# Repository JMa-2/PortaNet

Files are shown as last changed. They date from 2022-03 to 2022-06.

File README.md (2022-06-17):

# ***PortaNet Guide***
---
## *TABLE OF CONTENTS*
- [Introduction](#introduction)
- [Hardware](#hardware)
    - [Hardware General](#hardware-general)
    - [Hardware Tools](#hardware-tools)
    - [Schematic](#schematic)
    - [PCB Layout](#pcb-layout)
    - [BOM](#bom)
- [Software](#software)
    - [Software General](#software-general)
    - [Software Tools](#software-tools)
    - [Architecture](#architecture)
    - [Building](#building--flashing)
- [How to Use](#how-to-use)
    - [Use General](#use-general)
    - [PuTTy](#putty)
    - [Console Commands](#console-commands)
<br>
<br>
<br>

## *INTRODUCTION*
The PortaNet is a wifi access point (AP) using the Espressif ESP32-C3FH4 microcontroller. The PortaNet holds the shape and connection types of a typical USB stick. The AP's settings can be modified via a serial console. At this point PuTTy is the only tested terminal emulator software for use with PortaNet.

<br>

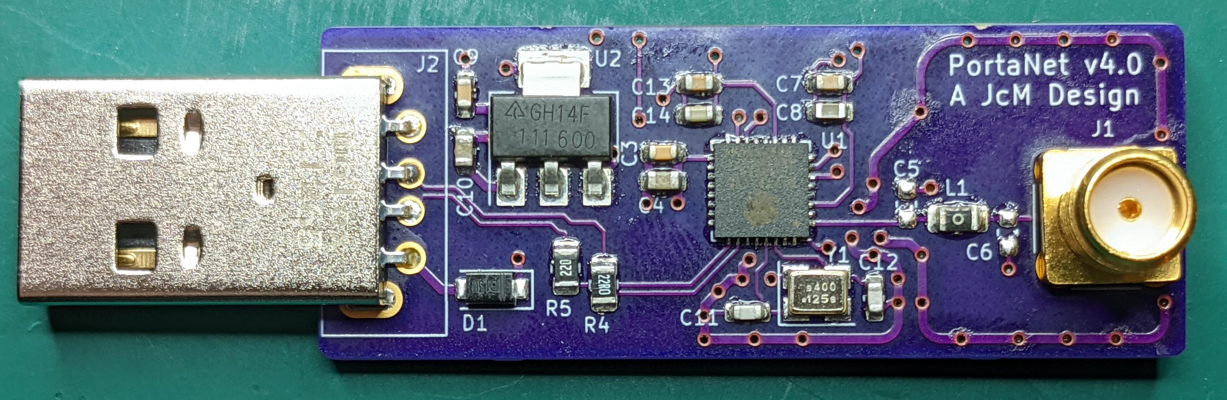
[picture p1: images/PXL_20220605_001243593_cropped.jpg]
PortaNet v4.0


<br>
<br>
<br>

## *HARDWARE*
### Hardware General
The critical component consists of the [Espressif ESP32-C3FH4](https://www.espressif.com/en/products/socs/esp32-c3). The ESP32-C3FH4 microcontroller is a ESP32-C3 variant with 4MB internal flash. Simply buying the "normal" ESP32-C3 variant will not suffice due to the lack of internal flash.

The design utilizes a 50 &Omega; impedance, 2.4 GHz wifi antenna. Antennas such as [this](https://www.amazon.com/gp/product/B07D1Z3W7T/ref=ppx_yo_dt_b_search_asin_title?ie=UTF8&psc=1) and [this](https://www.amazon.com/gp/product/B0991PKTDL/ref=ppx_yo_dt_b_search_asin_title?ie=UTF8&psc=1) have worked successfully. There is an unused &pi;-matching circuit that could aid in supporting other antennas.

### Hardware Tools
KiCad v6 was utilized as the EDA tool. The KiCad project can be found in the [hardware directory](hardware/kicad/PortaNet/). Additionally my [KiCad Library](http://192.168.1.19:3000/JMa/KiCad_Library) may contain needed symbols and footprints that the project references.

### Schematic
The current schematic can be seen [here](hardware/kicad/PortaNet_SCH.pdf). 

On page 2 of the schematic, the only oddity worth explaining is the NC of C2. Having C2 installed results in the GPIO9 (pin 15) being pulled low. Resulting in the firmware getting stuck in the bootloader.

On page 3 of the schematic, lives the unused &pi;-matching circuit labeled `Antenna`. If the &pi;-matching circuit does not want to be used, then `L1` should be shorted with a 0 &Omega; resistor.

On page 3 also lives the `Crystal` section. While the load capacitors are labeled 7pF, 8pF caps work with no issues thus far. 

### PCB Layout
The board layout consists of 4 layers, with components on both the top and bottom layers. 

The layer structure consists of the top layer being a signal layer, the second and third layer being GND layers, and the bottom layer being a PWR/signal layer. The top layer or layer 1 of the board is structured to isolate noise sources from other hardware sections. The sub-circuits on the top layer are split into PWR/USB, microcontroller (uC), crystal (XTAL), and radio frequency (RF) sections. GND traces with vias surround the RF and XTAL sections of the top layer.

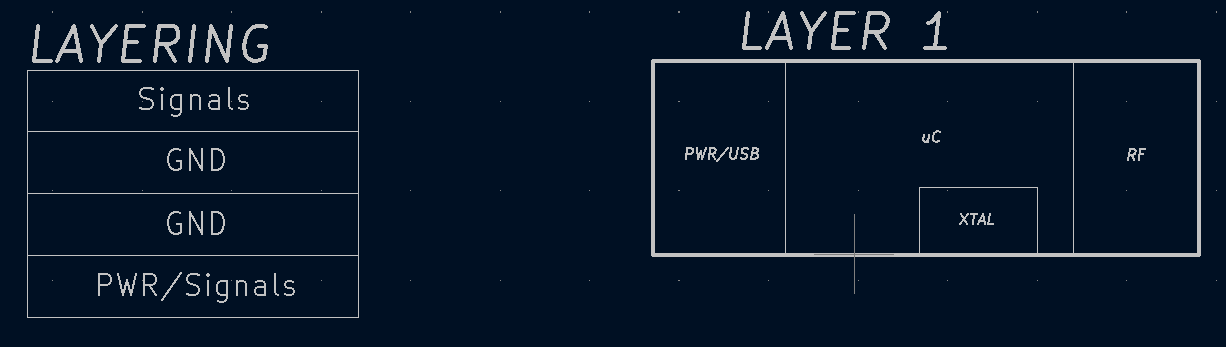
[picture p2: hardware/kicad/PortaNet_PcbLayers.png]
PCB Layout

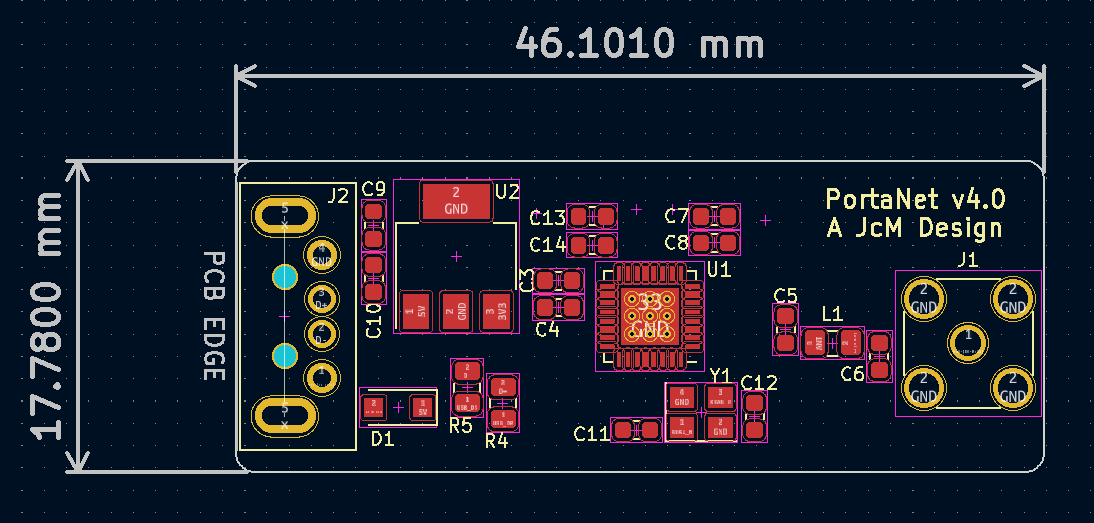
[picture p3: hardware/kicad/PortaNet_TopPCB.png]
Top Layer Routing


### BOM
The BOM can be found [here](hardware/kicad/PortaNet/PortaNet.csv). As well as a copy and paste is below. It is again important to note that **the ESP32-C3 part purchased must be a part that contains internal flash.**

| Ref | Qnty | Value | Cmp name | Footprint |
|---|---|---|---|---|
| C1, | 1 | 1uF | C_Small | Capacitor_SMD:C_0603_1608Metric |
| C2, | 1 | NC | C_Small | Capacitor_SMD:C_0603_1608Metric |
| C3, C7, C13, | 3 | 0.1uF | C_Small | Capacitor_SMD:C_0603_1608Metric |
| C4, C8, C10, C14, | 4 | 10uF | C_Small | Capacitor_SMD:C_0603_1608Metric |
| C5, C6, | 2 | TBD | C_Small | Capacitor_SMD:C_0603_1608Metric |
| C9, | 1 | .1uF | C_Small | Capacitor_SMD:C_0603_1608Metric |
| C11, C12, | 2 | 7pF | C_Small | Capacitor_SMD:C_0603_1608Metric |
| D1, | 1 | DSS13UTR | D_Schottky | Diode_SMD:D_SOD-123F |
| J1, | 1 | SMA | Conn_Coaxial | Connector_Coaxial:SMA_Amphenol_132134_Vertical |
| J2, | 1 | Molex 0480370001 | USB_A | JoesFootprints:Molex_0480370001 |
| L1, | 1 | TBD | L | Inductor_SMD:L_0805_2012Metric_Pad1.15x1.40mm_HandSolder |
| R1, R2, R3, | 3 | 10k | R_Small_US | Resistor_SMD:R_0805_2012Metric |
| R4, R5, | 2 | 22 | R_Small_US | Resistor_SMD:R_0805_2012Metric |
| SW1, | 1 | 434133025816 | SW_SPST | Button_Switch_SMD:SW_Push_1P1T_NO_Vertical_Wuerth_434133025816  |
| U1, | 1 | ESP32-C3 | ESP32-C3 | Package_DFN_QFN:QFN-32-1EP_5x5mm_P0.5mm_EP3.3x3.3mm_ThermalVias |
| U2, | 1 | AP2114HA-3.3TRG1 | AP2114HA-3.3TRG1 | Package_TO_SOT_SMD:SOT-223-3_TabPin2 |
| Y1, | 1 | FL400WFQA1 | Crystal_GND24 | Crystal:Crystal_SMD_3225-4Pin_3.2x2.5mm |

<br>
<br>
<br>

## *SOFTWARE*
### Software General
The firmware is written in C using [Espressif's IOT Development Framework (ESP-IDF)](https://www.espressif.com/en/products/sdks/esp-idf#:~:text=ESP%2DIDF%20is%20Espressif's%20official,as%20C%20and%20C%2B%2B.). The software utilizes [FreeRTOS](https://www.freertos.org/) as part of the ESP-IDF as well. 

### Software Tools
The software used `ESP-IDF v5.0-dev-3032-g7e71c0cff2-dirty`. The ESP-IDF can be found [here](https://github.com/espressif/esp-idf).

### Architecture
The software utilizes an RTOS variation of [A JcM Architecture](http://192.168.1.19:3000/JMa/JcmArch). Architecture formats can be seen [here](firmware/)

Two threads exists in the software. The first thread, which has the highest priority, is the `Access Point Thread`. The second thread, which has a lower priority compared to the `Access Point Thread`, is the `Console Thread`. The `Access Point Thread` is controlling the wifi soft-AP and the `Console Thread` is controlling the serial console processes that make requests to the `Access Point Interface`. 

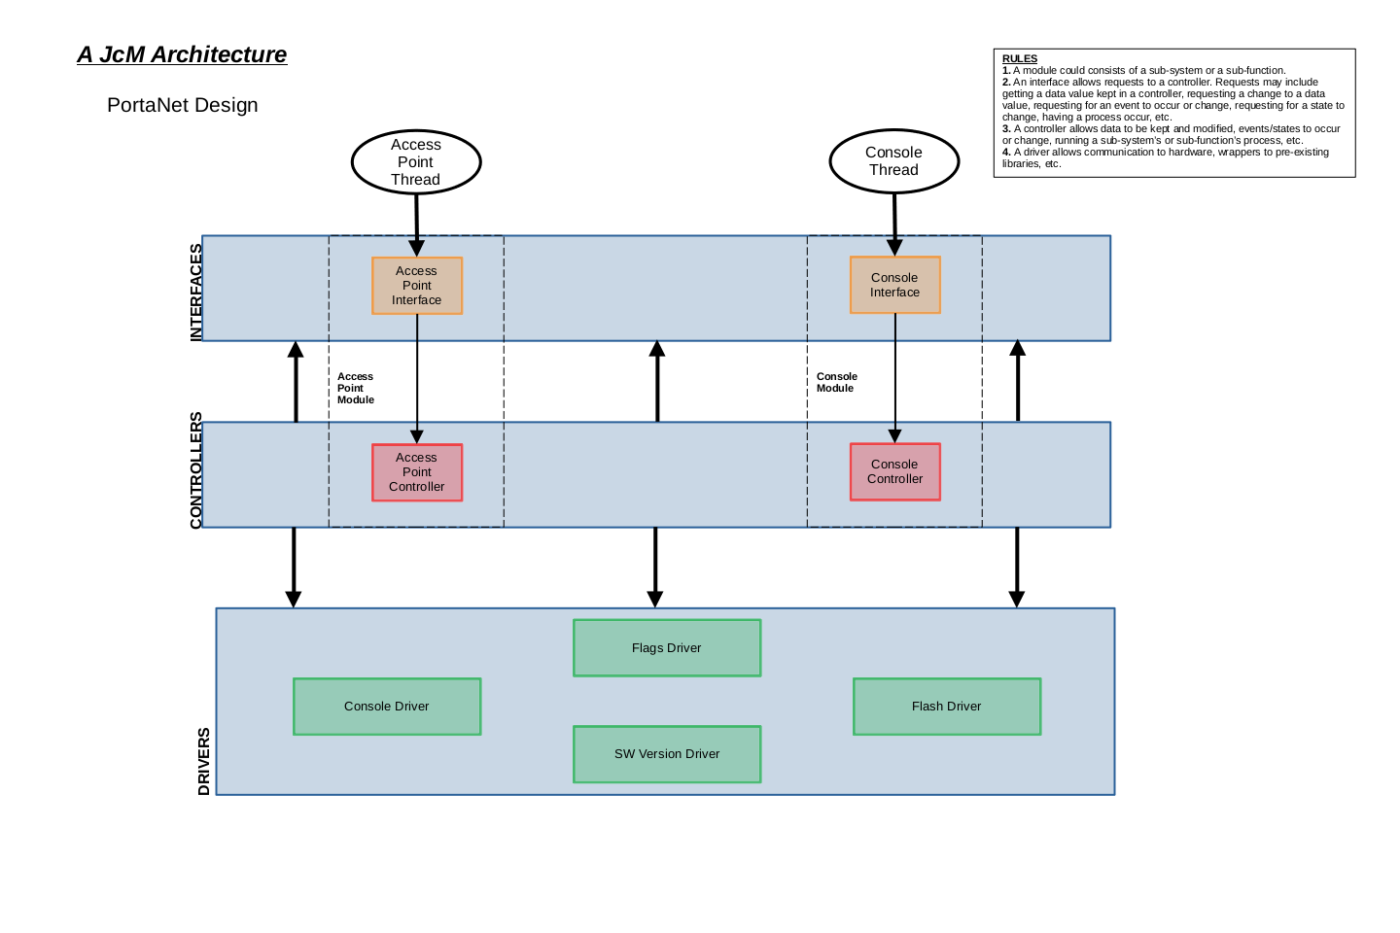
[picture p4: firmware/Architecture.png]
PortaNet SW Architecture


### Building & Flashing
1. Clone the repo<br>
`git clone http://192.168.1.19:3000/JMa/PortaNet.git`

2. Enter the firmware folder<br>
`cd PortaNet/firmware/PortaNet/`

3. Source the ESP-IDF export script from proper location<br>
example: `. ~/esp-idf/export.sh`

4. Ensure the target is set to the ESP32-C3<br>
`idf.py set-target esp32c3`

5. Build the project<br>
`idf.py build`

6. Flash the device<br>
`idf.py -p PORT flash`

<br>

If issues arise, Espressif has good documentation located [here](https://docs.espressif.com/projects/esp-idf/en/latest/esp32c3/get-started/linux-macos-setup.html).

<br>
<br>
<br>

## *HOW TO USE*
### Use General
Since the device uses USB 2.0, the operating voltage is 5V. Typical PC USB receptacles work just fine and even phone/device charging bricks should work without issue. The device draws less that 100mA so there shouldn't be power rating issues to monitor.

### PuTTy
At this point, PuTTy is the only terminal emulator that the device has really been tested with. PicoCom, the linux utility, appears to work as well.

PuTTy can be downloaded from [here](https://www.putty.org/) and it is widely used enough to easily find tutorials via Google or Youtube. 

### Console Commands
`help`<br>
Print the list of registered commands.

`status`<br>
Status of the AP which includes info such as the SSID, password, max number of connections, and wifi channel.

`reset`<br>
Reset the AP to its default credentials

`on`<br>
Turn on the AP.

`off`<br>
Turn off the AP.

`devices`<br>
Show info on currently connected devices.

`ssid <NAME>`<br>
Request new SSID of AP.

`password <PW>`<br>
Request new password of AP.

`maxconn <#>`<br>
Request new number of max connection of the AP.

`restart`<br>
Request the AP to restart.

`version`<br>
Request the current software version.

`channel <#>`<br>
Request new wifi channel of the AP.

<br>
<br>
<br>

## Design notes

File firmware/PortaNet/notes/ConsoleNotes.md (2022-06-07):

# ***CONSOLE NOTES***
***

## *INTERFACE*
`TaskConsole`

- interface to the task
<br><br/>

***

## *CONTROLLER*
`ConsoleController`

- handles the console processes to execute
<br><br/>

`RegisterAllCommands`

- registers all wanted commands
<br><br/>

`CmdReset`

- command function to request a reset of the wifi access point to its defualt credentials 
<br><br/>

`RegisterReset`

- register the reset command
<br><br/>

`CmdRestart`

- command function to request a restart of the wifi access point
<br><br/>

`RegisterRestart`

- register the restart command
<br><br/>

`CmdOn`

- command function to request the wifi access point on
<br><br/>

`RegisterOn`

- register the on command
<br><br/>

`CmdOff`

- command function to request the wifi access point off
<br><br/>

`RegisterOff`

- register the off command
<br><br/>

`CmdStatus`

- command function to request the status of the wifi access point. The status info should include the network name, the network password, the max number of connected devices allowed, and the current wifi channel.
<br><br/>

`RegisterStatus`

- register the status command
<br><br/>

`CmdDevices`

- command function to show the info of the currently connected stations/devices
<br><br/>

`RegisterDevices`

- register the devices command
<br><br/>

`CmdSsid`

- command function to request a change to the wifi access point's SSID and restart the wifi access point
- input arg of string
<br><br/>

`RegisterSsid`

- register the SSID command
<br><br/>

`CmdPassword`

- command function to request a change to the wifi access point's password and restart the wifi access point
- input arg of string
<br><br/>

`RegisterPassword`

- register the password command
<br><br/>

`CmdMaxConn`

- command function to request a change to the wifi access point's max number of connections and restart the wifi access point
- input arg of int
<br><br/>

`RegisterMaxConn`

- register the maxconn command
<br><br/>

`CmdSwVersion`

- command function to request the version of the firmware in use
<br><br/>

`RegisterSwVersion`

- register the software version command
<br><br/>

`CmdChannel`

- command function to request the wifi channel be changed
<br><br/>

`RegisterChannel`

- register the wifi channel change command

***

## *CONSOLE DRIVER*
`InitConsole`

- initialises the console, should only need to be called once
<br><br/>

***

## *COMMANDS*
`reset`

- resets the wifi access point with the defualt credentials
<br><br/>

`restart`

- restart the wifi access point 
<br><br/>

`on`

- turn on the wifi access point
<br><br/>

`off`

- turn off the wifi access point
<br><br/>

`status`

- show the status of the network if it running. The status info should include the network name, the network password, the max number of connected devices allowed, and the current wifi channel.
<br><br/>

`devices`

- shows the currently connected devices
<br><br/>

`ssid <newssid>`

- change the ssid name and restart the wifi access point
<br><br/>

`password <password>`

- change the password and restart the wifi access point
<br><br/>

`maxconn <connections>`

- change the number of max device connections and restart the wifi access point 
<br><br/>

`version`

- shows the current version of firmware

`channel <#>`

- change the wifi channel and restart the access point

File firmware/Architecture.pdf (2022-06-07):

## Access Point Thread

### Access Point

### Interface

### Access Point Controller

### Flags Driver

Console Driver | Flash Driver

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
## RIV

E

R

S

Access
Point
Module

## Console Thread

### Console

### Interface

### Console

### Controller

Console
Module

# A JcM Architecture

# PortaNet Design

RULES
1. A module could consists of a sub-system or a sub-function.

### 2. An interface allows requests to a controller. Requests may include

getting a data value kept in a controller, requesting a change to a data value, requesting for an event to occur or change, requesting for a state to change, having a process occur, etc.

### 3. A controller allows data to be kept and modified, events/states to occur

or change, running a sub-system’s or sub-function’s process, etc.

### 4. A driver allows communication to hardware, wrappers to pre-existing

libraries, etc.

### SW Version Driver

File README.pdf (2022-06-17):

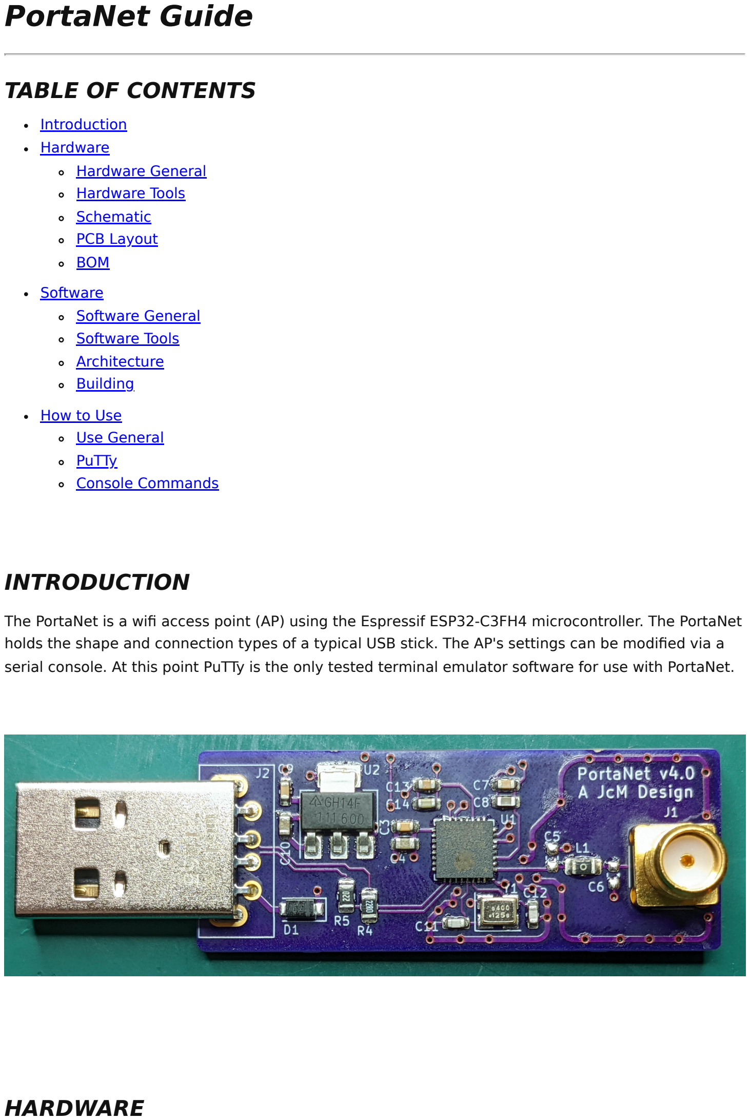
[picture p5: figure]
PortaNet Guide; TABLE OF CONTENTS; Introduction Hardware Hardware General Hardware Tools Schematic PCB Layout BOM; Software Software General Software Tools Architecture Building; How to Use Use General PuTTy Console Commands; INTRODUCTION; HARDWARE

The PortaNet is a wifi access point (AP) using the Espressif ESP32-C3FH4 microcontroller. The PortaNet holds the shape and connection types of a typical USB stick. The AP's settings can be modified via a serial console. At this point PuTTy is the only tested terminal emulator software for use with PortaNet.

Hardware General

The critical component consists of the Espressif ESP32-C3FH4. (https://www.espressif.com/en/products/socs/esp32-c3) The ESP32-C3FH4 microcontroller is a ESP32-C3 variant with 4MB internal flash. Simply buying the "normal" ESP32-C3 variant will not suffice due to the lack of internal flash.

The design utilizes a 50 Ω impedance, 2.4 GHz wifi antenna. Antennas such as this (https://www.amazon.com/gp/product/B07D1Z3W7T/ref=ppx_yo_dt_b_search_asin_title?ie=UTF8&psc=1) and this (https://www.amazon.com/gp/product/B0991PKTDL/ref=ppx_yo_dt_b_search_asin_title?ie=UTF8&psc=1) have worked successfully. There is an unused π-matching circuit that could aid in supporting other antennas.

Hardware Tools

KiCad v6 was utilized as the EDA tool. The KiCad project can be found in the hardware directory. (http://localhost:33777/hardware/kicad/PortaNet/) Additionally my KiCad Library (http://192.168.1.19:3000/JMa/KiCad_Library) may contain needed symbols and footprints that the project references.

Schematic

The current schematic can be seen here. (http://localhost:33777/hardware/kicad/PortaNet_SCH.pdf)

On page 2 of the schematic, the only oddity worth explaining is the NC of C2. Having C2 installed results in the GPIO9 (pin 15) being pulled low. Resulting in the firmware getting stuck in the bootloader.

On page 3 of the schematic, lives the unused π-matching circuit labeled Antenna . If the π-matching circuit does not want to be used, then L1 should be shorted with a 0 Ω resistor.

On page 3 also lives the Crystal section. While the load capacitors are labeled 7pF, 8pF caps work with no issues thus far.

PCB Layout

The board layout consists of 4 layers, with components on both the top and bottom layers.

The layer structure consists of the top layer being a signal layer, the second and third layer being GND layers, and the bottom layer being a PWR/signal layer. The top layer or layer 1 of the board is structured to isolate noise sources from other hardware sections. The sub-circuits on the top layer are split into PWR/USB, microcontroller (uC), crystal (XTAL), and radio frequency (RF) sections. GND traces with vias surround the RF and XTAL sections of the top layer.


BOM

The BOM can be found here. (http://localhost:33777/hardware/kicad/PortaNet/PortaNet.csv) As well as a copy and paste is below. It is again important to note that the ESP32-C3 part purchased must be a part that contains internal flash.

Ref | Qnty | Value | Cmp name | Footprint
C1, | 1 | 1uF | C_Small | Capacitor_SMD:C_0603_1608Metric
C2, | 1 | NC | C_Small | Capacitor_SMD:C_0603_1608Metric

C3,
C7, C13, | 3 | 0.1uF | C_Small | Capacitor_SMD:C_0603_1608Metric

C4,
C8,
C10,
C14,
4 | 10uF | C_Small | Capacitor_SMD:C_0603_1608Metric

C5,
C6,
| 2 | TBD | C_Small | Capacitor_SMD:C_0603_1608Metric
C9, | 1 | .1uF | C_Small | Capacitor_SMD:C_0603_1608Metric

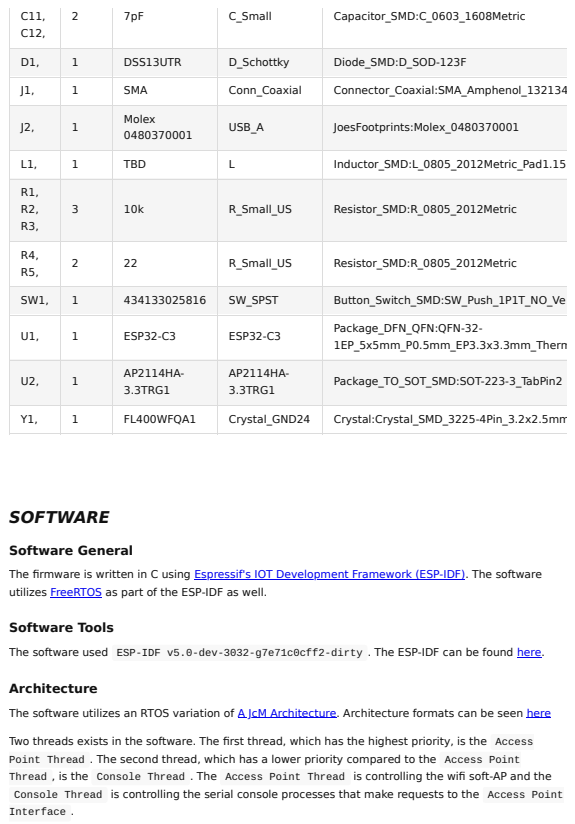
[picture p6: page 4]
C_Small; Capacitor_SMD:C_0603_1608Metric; DSS13UTR; D_Schottky; Diode_SMD:D_SOD-123F; SMA; Conn_Coaxial; Connector_Coaxial:SMA_Amphenol_132134; Molex 0480370001; USB_A; JoesFootprints:Molex_0480370001; TBD; Inductor_SMD:L_0805_2012Metric_Pad1.15; R_Small_US; Resistor_SMD:R_0805_2012Metric; SW_SPST; Button_Switch_SMD:SW_Push_1P1T_NO_Ve; ESP32-C3; Package_DFN_QFN:QFN-32-; 1EP_5x5mm_P0.5mm_EP3.3x3.3mm_Therm; AP2114HA- 3.3TRG1; Package_TO_SOT_SMD:SOT-223-3_TabPin2; FL400WFQA1; Crystal_GND24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

The firmware is written in C using Espressif's IOT Development Framework (ESP-IDF). (https://www.espressif.com/en/products/sdks/esp-idf) The software
utilizes FreeRTOS (https://www.freertos.org/) as part of the ESP-IDF as well.

The software used ESP-IDF v5.0-dev-3032-g7e71c0cff2-dirty . The ESP-IDF can be found here. (https://github.com/espressif/esp-idf)

The software utilizes an RTOS variation of A JcM Architecture. (http://192.168.1.19:3000/JMa/JcmArch) Architecture formats can be seen here (http://localhost:33777/firmware/)

Two threads exists in the software. The first thread, which has the highest priority, is the Access
Point Thread . The second thread, which has a lower priority compared to the Access Point
Thread , is the Console Thread . The Access Point Thread is controlling the wifi soft-AP and the
Console Thread is controlling the serial console processes that make requests to the Access Point
Interface .

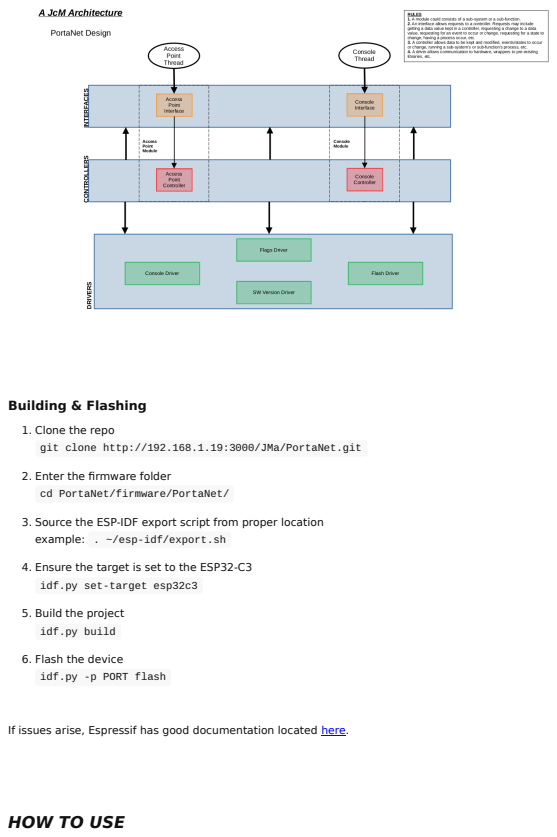
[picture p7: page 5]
Building & Flashing

1. Clone the repo
git clone http://192.168.1.19:3000/JMa/PortaNet.git

2. Enter the firmware folder
cd PortaNet/firmware/PortaNet/

3. Source the ESP-IDF export script from proper location
example: . ~/esp-idf/export.sh

4. Ensure the target is set to the ESP32-C3
idf.py set-target esp32c3

5. Build the project
idf.py build

6. Flash the device
idf.py -p PORT flash

If issues arise, Espressif has good documentation located here. (https://docs.espressif.com/projects/esp-idf/en/latest/esp32c3/get-started/linux-macos-setup.html)

HOW TO USE

Use General

Since the device uses USB 2.0, the operating voltage is 5V. Typical PC USB receptacles work just fine and even phone/device charging bricks should work without issue. The device draws less that 100mA so there shouldn't be power rating issues to monitor.

PuTTy

At this point, PuTTy is the only terminal emulator that the device has really been tested with. PicoCom, the linux utility, appears to work as well.

PuTTy can be downloaded from here (https://www.putty.org/) and it is widely used enough to easily find tutorials via Google or Youtube.

Console Commands

help
Print the list of registered commands.

status
Status of the AP which includes info such as the SSID, password, max number of connections, and wifi channel.

reset
Reset the AP to its default credentials

on
Turn on the AP.

off
Turn off the AP.

devices
Show info on currently connected devices.

ssid <NAME>
Request new SSID of AP.

password <PW>
Request new password of AP.

maxconn <#>
Request new number of max connection of the AP.

restart
Request the AP to restart.

version
Request the current software version.

channel <#>
Request new wifi channel of the AP.

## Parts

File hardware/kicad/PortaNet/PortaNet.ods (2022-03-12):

Component Count: | 32
Ref | Qnty | Value | Cmp name | Footprint | Description | Vendor
AE1, | 1 | ANT3216LL00R2400A | Antenna_Shield | JoesFootprints:ANT3216LL00R2400A | Antenna with extra pin for shielding
C3, | 1 | 0.1uF | C_Small | Capacitor_SMD:C_0603_1608Metric | Unpolarized capacitor, small symbol
C4, C10, | 2 | 10uF | C_Small | Capacitor_SMD:C_0603_1608Metric | Unpolarized capacitor, small symbol
C9, | 1 | .1uF | C_Small | Capacitor_SMD:C_0603_1608Metric | Unpolarized capacitor, small symbol
C11, C12, | 2 | 7pF | C_Small | Capacitor_SMD:C_0603_1608Metric | Unpolarized capacitor, small symbol
D1, D4, | 2 | DSS13UTR | D_Schottky | Diode_SMD:D_SOD-123F | Schottky diode
D2, | 1 | L196L-UEC-TR | LED | LED_SMD:LED_0603_1608Metric | Light emitting diode
D3, | 1 | L196L-QYC-TR | LED | LED_SMD:LED_0603_1608Metric | Light emitting diode
J1, | 1 | UART | Conn_01x03 | Connector_PinSocket_2.54mm:PinSocket_1x03_P2.54mm_Vertical | Generic connector, single row, 01x03, script generated (kicad-library-utils/schlib/autogen/connector/)
J2, | 1 | Molex 0480370001 | USB_A | JoesFootprints:Molex_0480370001 | USB Type A connector
J3, | 1 | OLED_PINS | Conn_01x04 | JoesFootprints:OLED_0.91in_i2c | Generic connector, single row, 01x04, script generated (kicad-library-utils/schlib/autogen/connector/)
J4, | 1 | GRPB052VWVN-RC | Conn_ARM_JTAG_SWD_10 | Connector_PinHeader_1.27mm:PinHeader_2x05_P1.27mm_Vertical | Cortex Debug Connector, standard ARM Cortex-M SWD and JTAG interface
R1, | 1 | 10k | R_Small_US | Resistor_SMD:R_0805_2012Metric | Resistor, small US symbol
R2, R3, R4, | 3 | 0 | R_Small_US | Resistor_SMD:R_0805_2012Metric | Resistor, small US symbol
R5, R6, | 2 | 4.7k | R_Small_US | Resistor_SMD:R_0805_2012Metric | Resistor, small US symbol
R7, R8, | 2 | 22 | R_Small_US | Resistor_SMD:R_0805_2012Metric | Resistor, small US symbol
R9, R10, | 2 | 1k | R_Small_US | Resistor_SMD:R_0805_2012Metric | Resistor, small US symbol
TP3, TP4, TP5, | 3 | TestPoint | TestPoint | TestPoint:TestPoint_Pad_1.0x1.0mm | test point
U1, | 1 | ESP32-C3 | ESP32-C3 | Package_DFN_QFN:QFN-32-1EP_5x5mm_P0.5mm_EP3.3x3.3mm_ThermalVias
U2, | 1 | AP2114HA-3.3TRG1 | AP2114HA-3.3TRG1 | Package_TO_SOT_SMD:SOT-223-3_TabPin2
Y1, | 1 | FL400WFQA1 | Crystal_GND24 | Crystal:Crystal_SMD_3225-4Pin_3.2x2.5mm | Four pin crystal, GND on pins 2 and 4

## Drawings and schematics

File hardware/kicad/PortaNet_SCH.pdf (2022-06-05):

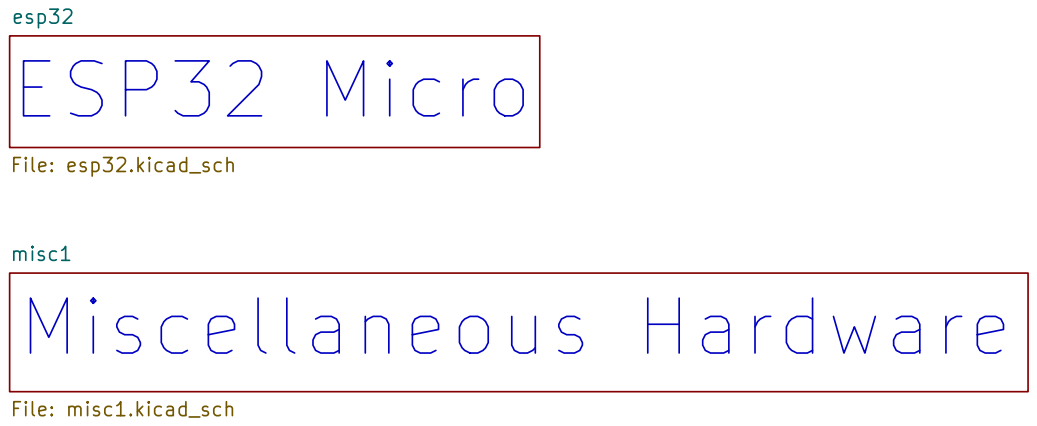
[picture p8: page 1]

File: esp32.kicad_sch misc1 File: misc1.kicad_sch Miscellaneous Hardware

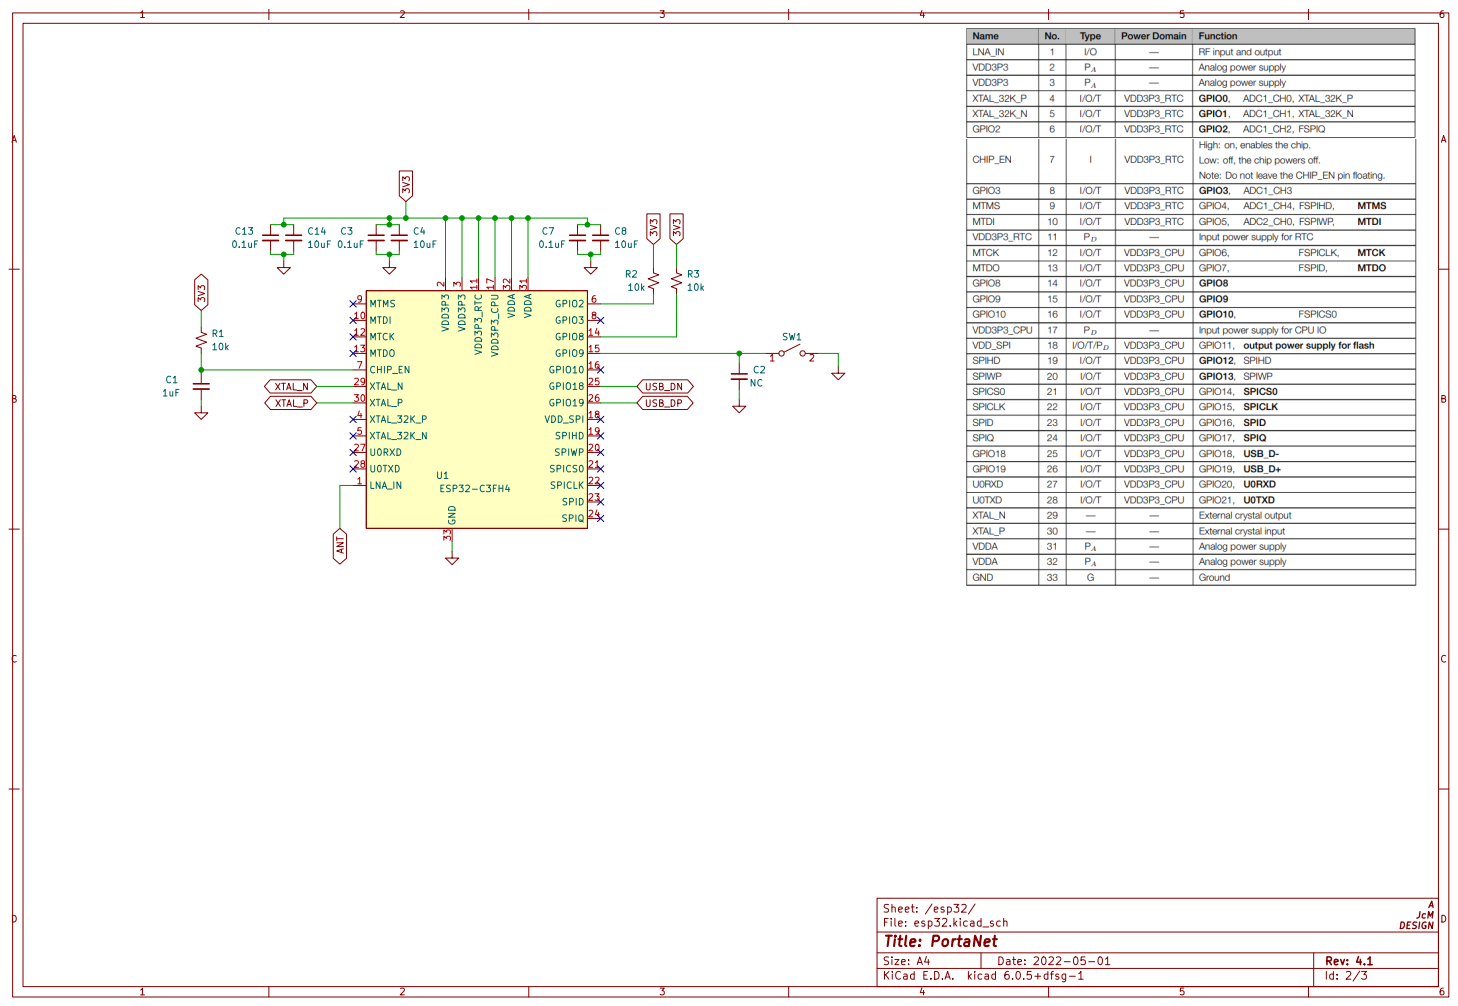
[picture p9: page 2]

3 XTAL_P 30 VDDA 31 VDDA 32 GND 33 XTAL_32K_P 4 XTAL_32K_N 5 GPIO2 6 CHIP_EN 7 GPIO3 8 MTMS 9 U1ESP32-C3FH4 C8

2 SPIWP 20 SPICS0 21 SPICLK 22 SPID 23 SPIQ 24 GPIO18 25 GPIO19 26 U0RXD 27 U0TXD 28 XTAL_N 29 VDD3P3

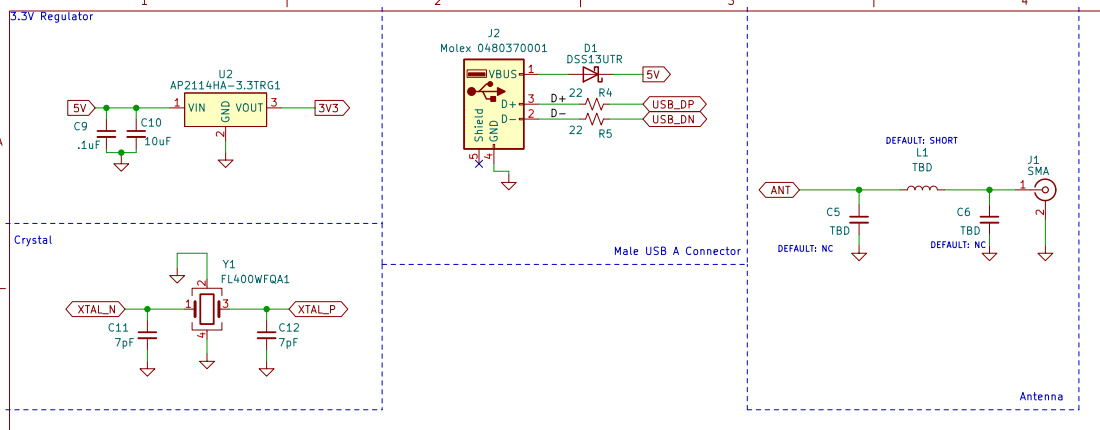
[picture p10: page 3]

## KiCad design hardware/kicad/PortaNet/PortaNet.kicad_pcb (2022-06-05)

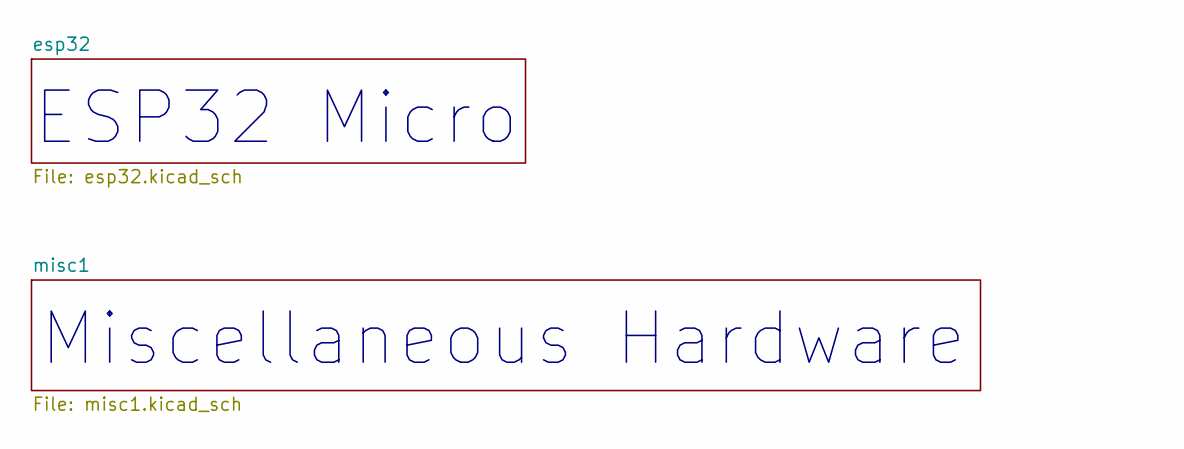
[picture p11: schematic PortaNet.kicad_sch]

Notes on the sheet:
Miscellaneous Hardware
ESP32 Micro

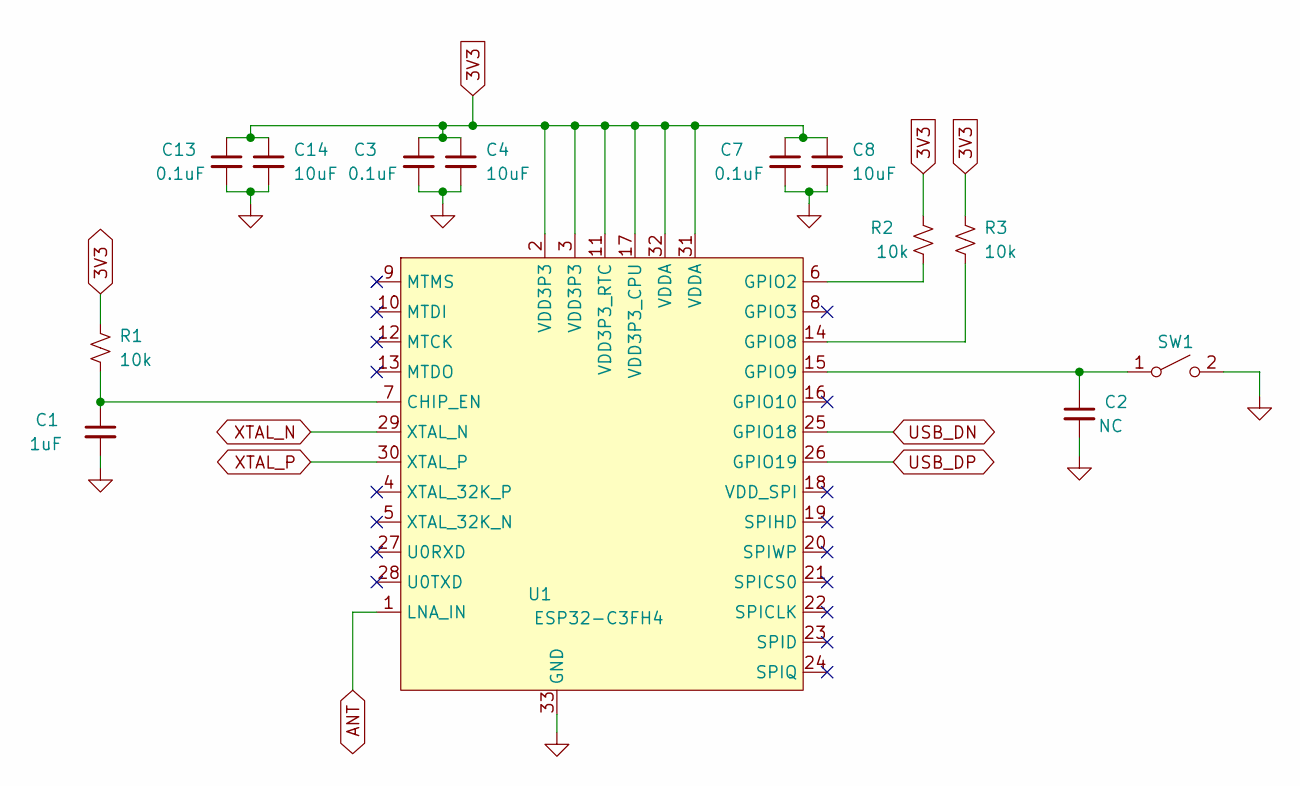
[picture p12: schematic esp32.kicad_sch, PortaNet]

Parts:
C1: 1uF; C_0603_1608Metric
C2: NC; C_0603_1608Metric
C3, C7, C13: 0.1uF; C_0603_1608Metric
C4, C8, C14: 10uF; C_0603_1608Metric
R1, R2, R3: 10k; R_0805_2012Metric
SW1: 434133025816; SW_Push_1P1T_NO_Vertical_Wuerth_434133025816
U1: ESP32-C3FH4; QFN-32-1EP_5x5mm_P0.5mm_EP3.3x3.3mm_ThermalVias

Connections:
3V3: C3.1, C4.1, C7.1, C8.1, C13.1, C14.1, R1.2, R2.2, R3.2, U1.2 (VDD3P3), U1.3 (VDD3P3), U1.11 (VDD3P3_RTC), U1.17 (VDD3P3_CPU), U1.31 (VDDA), U1.32 (VDDA); also elsewhere on the board
ANT: U1.1 (LNA_IN); also elsewhere on the board
GND: C1.2, C2.2, C3.2, C4.2, C7.2, C8.2, C13.2, C14.2, SW1.2 (B), U1.33 (GND); also elsewhere on the board
unnamed: C1.1, R1.1, U1.7 (CHIP_EN)
unnamed: C2.1, SW1.1 (A), U1.15 (GPIO9)
unnamed: R3.1, U1.14 (GPIO8)
unnamed: R2.1, U1.6 (GPIO2)
USB_DN: U1.25 (GPIO18); also elsewhere on the board
USB_DP: U1.26 (GPIO19); also elsewhere on the board
XTAL_N: U1.29 (XTAL_N); also elsewhere on the board
XTAL_P: U1.30 (XTAL_P); also elsewhere on the board

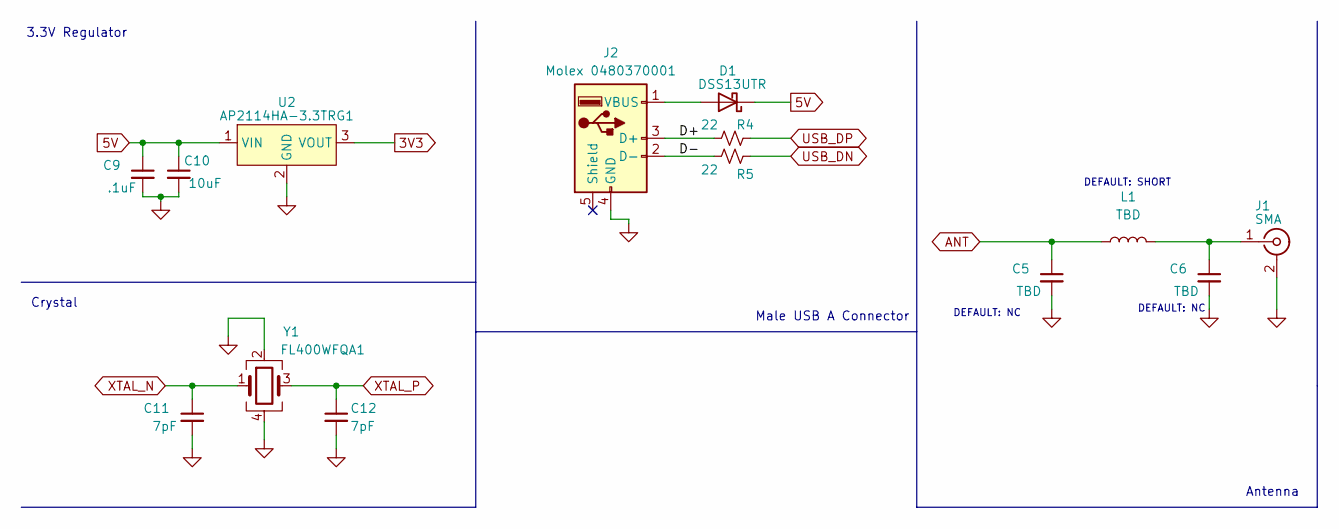
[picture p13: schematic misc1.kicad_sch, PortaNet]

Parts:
C5, C6: TBD; C_0603_1608Metric
C9: .1uF; C_0603_1608Metric
C10: 10uF; C_0603_1608Metric
C11, C12: 7pF; C_0603_1608Metric
D1: DSS13UTR; D_SOD-123F
J1: SMA; SMA_Amphenol_132134_Vertical
J2: Molex 0480370001; Molex_0480370001
L1: TBD; L_0805_2012Metric_Pad1.15x1.40mm_HandSolder
R4, R5: 22; R_0805_2012Metric
U2: AP2114HA-3.3TRG1; SOT-223-3_TabPin2
Y1: FL400WFQA1; Crystal_SMD_3225-4Pin_3.2x2.5mm

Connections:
3V3: U2.3 (VOUT); also elsewhere on the board
5V: C9.1, C10.1, D1.1 (K), U2.1 (VIN)
/misc1/D+: J2.3 (D+), R4.2
/misc1/D-: J2.2 (D-), R5.2
ANT: C5.1, L1.1; also elsewhere on the board
GND: C5.2, C6.2, C9.2, C10.2, C11.2, C12.2, J1.2 (Ext), J2.4 (GND), U2.2 (GND), Y1.2, Y1.4; also elsewhere on the board
unnamed: C6.1, J1.1 (In), L1.2
unnamed: D1.2 (A), J2.1 (VBUS)
USB_DN: R5.1; also elsewhere on the board
USB_DP: R4.1; also elsewhere on the board
XTAL_N: C11.1, Y1.1; also elsewhere on the board
XTAL_P: C12.1, Y1.3; also elsewhere on the board

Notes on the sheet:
Male USB A Connector
DEFAULT: SHORT
3.3V Regulator
Antenna
DEFAULT: NC
Crystal

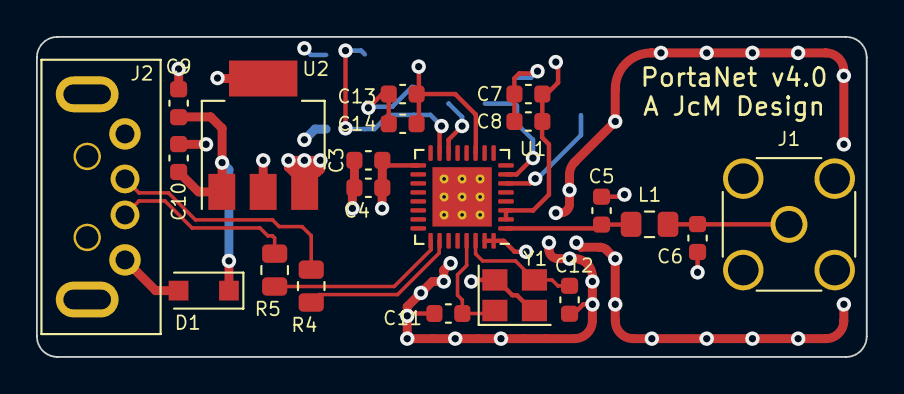
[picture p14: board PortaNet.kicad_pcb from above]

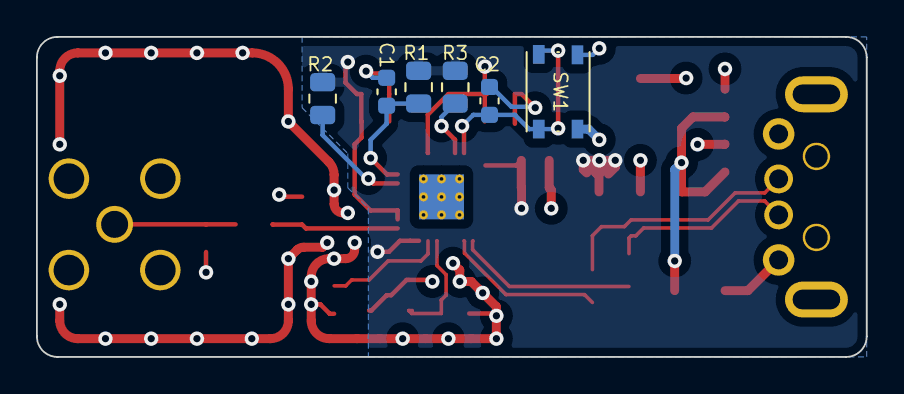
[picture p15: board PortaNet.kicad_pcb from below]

Board: 4 copper layers, 46.1 x 17.8 mm, 27 parts (6 on the bottom side), 16 nets.

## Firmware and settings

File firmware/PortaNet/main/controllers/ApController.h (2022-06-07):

#ifndef APCONTROLLER_H
#define APCONTROLLER_H

#include <stdbool.h>
#include <stdint.h>

#define MAX_SSID_LENGTH         32 //bytes
#define MIN_SSID_LENGTH         5  //bytes
#define MAX_PASSWORD_LENGTH     64 //bytes
#define MIN_PASSWORD_LENGTH     10 //bytes
#define MAX_NUMCONNECTIONS      10
#define MIN_NUMCONNECTIONS      2
#define MIN_WIFI_CHANNEL        3
#define MAX_WIFI_CHANNEL        7
#define WIFI_CHANNEL_ERROR      2   //TODO: figure out why this is needed

#define DEFAULT_SSID                "DefaultSsid"
#define DEFAULT_PASSWORD            "1234567890"
#define DEFAULT_NUMCONNECTIONS      3
#define DEFAULT_WIFI_CHANNEL        1

enum ApFlags {
    AP_FLAG_NET_UP      = 0b1 << 0,
    AP_FLAG_NEW_SSID    = 0b1 << 1,
    AP_FLAG_PW_CHANGE   = 0b1 << 2,
    AP_FLAG_RST_NET     = 0b1 << 3,
    AP_FLAG_NEW_MAXCONN = 0b1 << 4,
    AP_FLAG_REQ_OFF     = 0b1 << 5,
    AP_FLAG_REQ_ON      = 0b1 << 6,
    AP_FLAG_REQ_RESET   = 0b1 << 7,
    AP_FLAG_NEW_CHANNEL = 0b1 << 8
};


typedef struct ApData{
    char ssid[MAX_SSID_LENGTH];
    char password[MAX_PASSWORD_LENGTH];
    uint8_t maxConn;
    uint8_t channel;
}ApData;


/**
 * @brief set an access point flag high
 * 
 * @param flags flag or flags to set high from AP_FLAGS
 * @return true if all flags to be set went from low to high
 * @return false if any of the tags didn't go high or if flags were already high
 */
bool SetApFlag(unsigned int flags);


/**
 * @brief set a access point flag(s) low 
 * 
 * @param flags flag or flags to set low from AP_FLAGS
 * @return true if all flags to be reset when from high to low
 * @return false of any of the tags didn't go low or if flags were already low
 */
bool ResetApFlag(unsigned int flags);


/**
 * @brief see if flag(s) are set
 * 
 * @param flags to check if high
 * @return true if flags are high
 * @return false if any on the flags aren't high
 */
bool IsApFlagSet(unsigned int flags);


/**
 * @brief main access point controller function the interface should call
 * 
 * @param data access point data buffer to pass from interface to controller
 */
void AccessPointController(ApData data);


/**
 * @brief pass the number of max connections to the interface
 * 
 * @return uint8_t current number of allowed connection setting
 */
uint8_t PassMaxConnSetting(void);


/**
 * @brief pass the current number of connected devices to the interface
 * 
 * @return uint8_t current number of connected devices or a value of 11 if the a failure occured
 */
uint8_t PassNumConnDevices(void);


/**
 * @brief pass the current ssid name to the interface
 * 
 * @param str address where ssid name will be copied
 */
void PassSsid(char *str);


/**
 * @brief pass the current password to the inteface
 * 
 * @param str address where password will be copied
 */
void PassPassword(char *str);


/**
 * @brief pass the current list of macs
 * 
 * @param macbuffer buffer to pass the macs
 * @param ipbuffer buffer to pass the ips
 */
void PassStaInfo(uint8_t* macbuffer, uint32_t* ipbuffer);


/**
 * @brief pass the current wifi channel to the interface
 * 
 * @return uint8_t current wifi channel
 */
uint8_t PassWifiChannel(void);



#endif

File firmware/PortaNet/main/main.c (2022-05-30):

#include "sdkconfig.h"
#include "freertos/FreeRTOS.h"
#include "freertos/task.h"
#include "interfaces/ApInterface.h"
#include "interfaces/ConsoleInterface.h"

void app_main(void)
{
	xTaskCreate(&TaskAccessPoint, "TaskAccessPoint", 4096, NULL, 2, NULL);

	xTaskCreate(&TaskConsole, "TaskConsole", 4096, NULL, 1, NULL);
	
}

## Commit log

2022-03-08 init commit
    [PortaNet.kicad_pcb, PortaNet.kicad_sch, esp32.kicad_sch]
2022-03-08 update sch
    [PortaNet.kicad_sch, esp32.kicad_sch]
2022-03-08 add notes
    [PortaNet.kicad_sch, esp32.kicad_sch]
2022-03-09 eod commit
    [PortaNet.kicad_sch, esp32.kicad_sch, misc1.kicad_sch]
2022-03-12 first layout rev
    [PortaNet.kicad_pcb, PortaNet.kicad_sch, esp32.kicad_sch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]
2022-03-12 add bom
    [PortaNet.csv, PortaNet.kicad_sch, PortaNet.ods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]
2022-03-12 add gerbers
    [PortaNet-B_Cu.gbr, PortaNet-B_Mask.gbr, PortaNet-B_Paste.gbr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]
2022-03-22 modify flash driver and apcontroller
2022-03-25 kicad cache
2022-03-26 board v2 changes
    [PortaNet.kicad_pcb, PortaNet.kicad_sch, esp32.kicad_sch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]
2022-03-26 gerbers v2
    [PortaNet-B_Cu.gbr, PortaNet-B_Mask.gbr, PortaNet-B_Paste.gbr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]
2022-06-06 update arch with sw version driver
